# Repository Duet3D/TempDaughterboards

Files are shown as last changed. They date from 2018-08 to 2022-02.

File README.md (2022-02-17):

# TempDaughterboards

The Design files for [PT100](https://www.duet3d.com/PT100_DaughterBoard) and [Thermocouple](https://www.duet3d.com/TC_K_DaughterBoard) daughterboards for Duet boards

Current version 1.1, archive containes older versions

The designs are licensed under the CERN OHL v1.2

Documentation:
https://docs.duet3d.com/Duet3D_hardware/Accessories/Thermocouple_Daughterboard
https://docs.duet3d.com/en/Duet3D_hardware/Accessories/PT100_Temperature_Daughterboard

## Support requests

Please use the [forum](https://forum.duet3d.com) for support requests.

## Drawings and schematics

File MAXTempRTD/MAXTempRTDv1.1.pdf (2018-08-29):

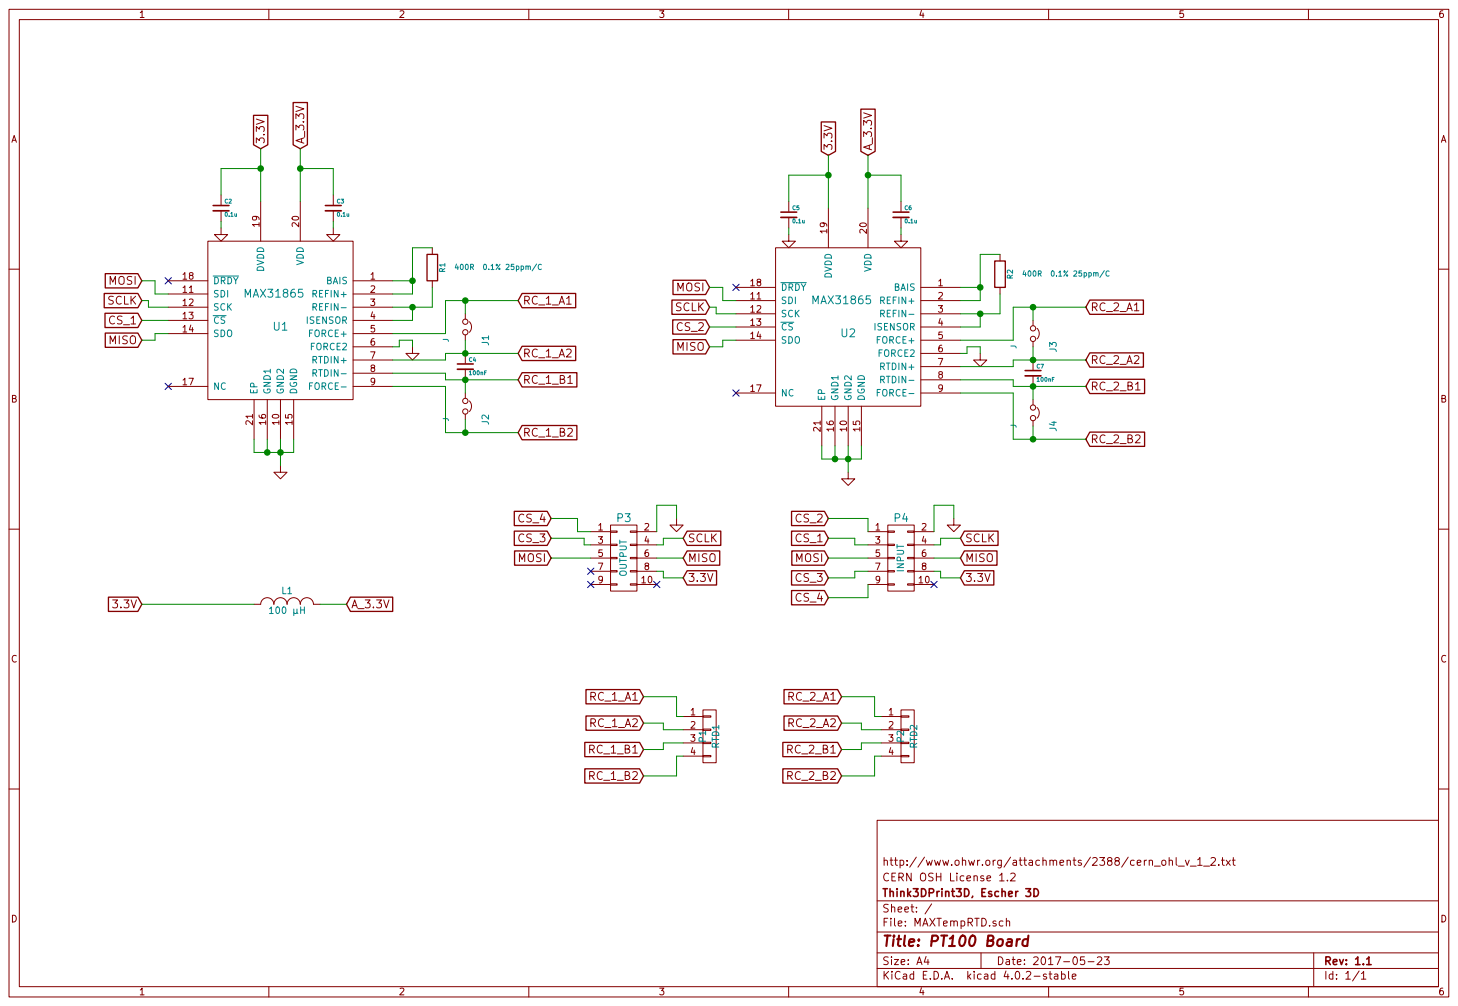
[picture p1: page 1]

http://www.ohwr.org/attachments/2388/cern_ohl_v_1_2.txt
CERN OSH License 1.2
File: MAXTempRTD.sch Sheet: / Think3DPrint3D, Escher 3D

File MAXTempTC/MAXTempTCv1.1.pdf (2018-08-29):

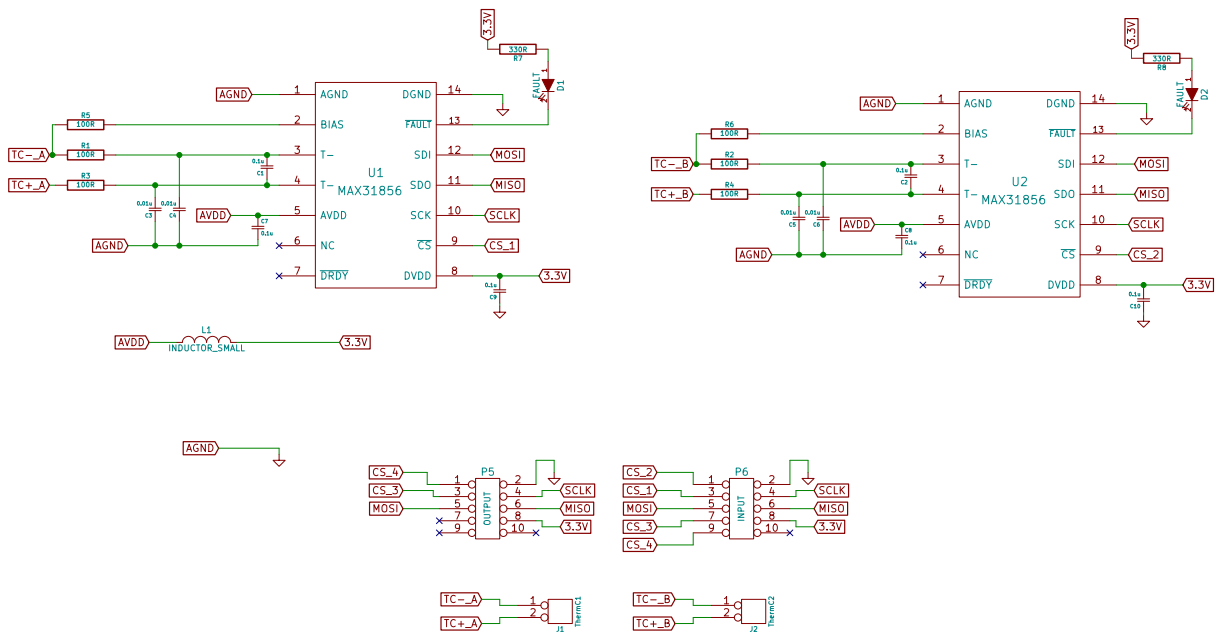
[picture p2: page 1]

http://www.ohwr.org/attachments/2388/cern_ohl_v_1_2.txt
CERN OSH License 1.2
File: MAXTempTC.sch Sheet: / Think3DPrint3D, Escher 3D

Id: 1/1 Title: MAX Temp Thermocouple Board

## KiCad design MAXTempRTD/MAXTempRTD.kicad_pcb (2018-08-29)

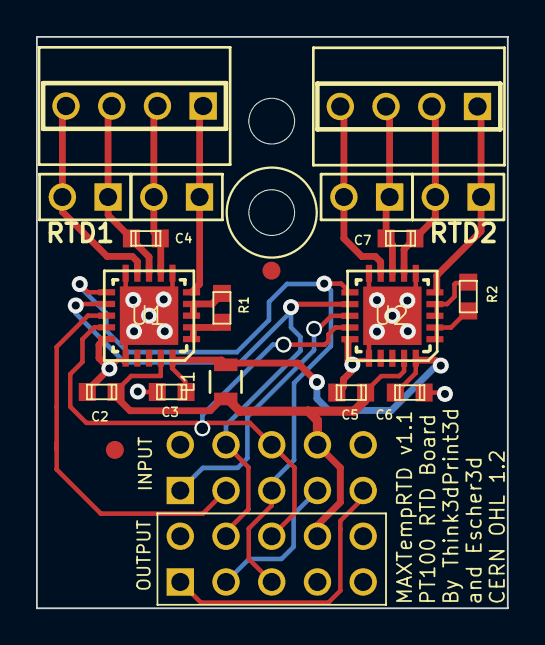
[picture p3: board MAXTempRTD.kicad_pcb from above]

Board: 2 copper layers, 26.2 x 31.7 mm, 19 parts (1 on the bottom side), 22 nets.

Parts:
C2, C3, C5, C6: 0.1u; C_0603
C4, C7: 100nF; C_0603
J1, J2, J3, J4: J; JUMPER
L1: 100 µH; R_0805
P1: RTD1; SCREW_TERMINAL_4x1
P2: RTD2; SCREW_TERMINAL_4x1
P3: OUTPUT; MAX_TEMP_DB
P4: INPUT; MAX_TEMP_DB_inv
R1, R2: 400R 0.1% 25ppm/C; R_0603
U1, U2: MAX31865; QFN20_5x5

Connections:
3.3V: C2.1, C5.1, L1.1, P3.8, P4.8, U1.19, U2.19
A_3.3V: C3.1, C6.1, L1.2, U1.20, U2.20
CS_1: P4.3, U1.13
CS_2: P4.1, U2.13
CS_3: P3.3, P4.7
CS_4: P3.1, P4.9
GND: C2.2, C3.2, C5.2, C6.2, P3.2, P4.2, U1.6, U1.10, U1.15, U1.16, U1.21, U2.6, U2.10, U2.15, U2.16, U2.21
MISO: P3.6, P4.6, U1.14, U2.14
MOSI: P3.5, P4.5, U1.11, U2.11
unnamed: R1.1, U1.1, U1.2
unnamed: R1.2, U1.3, U1.4
unnamed: R2.1, U2.1, U2.2
unnamed: R2.2, U2.3, U2.4
RC_1_A1: J1.1, P1.1, U1.5
RC_1_A2: C4.1, J1.2, P1.2, U1.7
RC_1_B1: C4.2, J2.1, P1.3, U1.8
RC_1_B2: J2.2, P1.4, U1.9
RC_2_A1: J3.1, P2.1, U2.5
RC_2_A2: C7.1, J3.2, P2.2, U2.7
RC_2_B1: C7.2, J4.1, P2.3, U2.8
RC_2_B2: J4.2, P2.4, U2.9
SCLK: P3.4, P4.4, U1.12, U2.12

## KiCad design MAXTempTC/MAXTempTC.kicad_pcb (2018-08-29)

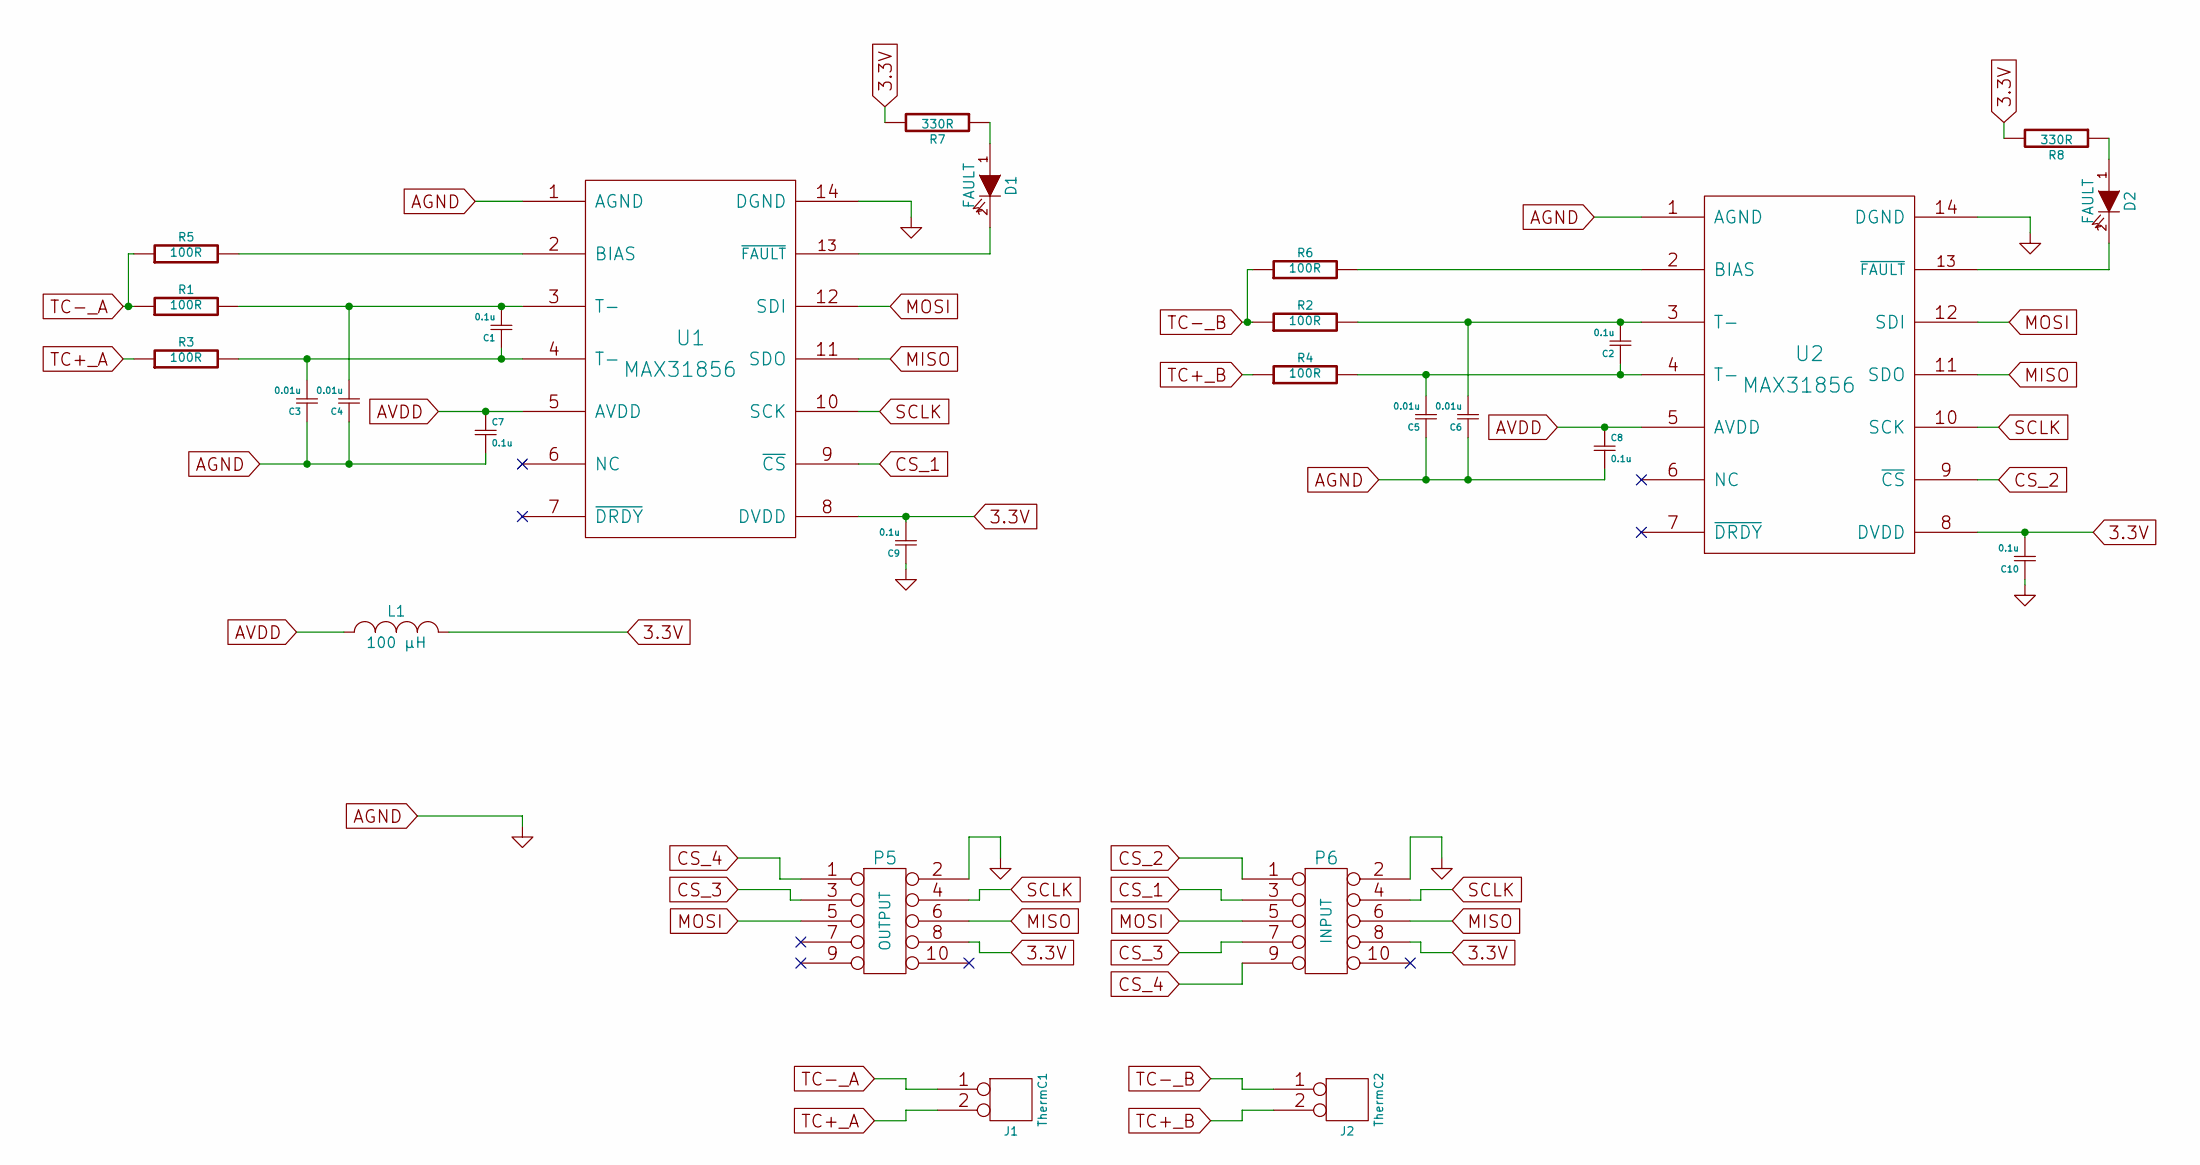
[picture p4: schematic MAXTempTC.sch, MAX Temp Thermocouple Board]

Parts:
C1, C2, C7, C8, C9, C10: 0.1u; C_0603
C3, C4, C5, C6: 0.01u; C_0603
D1, D2: FAULT; D_0603
J1: ThermC1; PIN_ARRAY_2X1
J2: ThermC2; PIN_ARRAY_2X1
L1: 100 µH; R_0805
P5: OUTPUT; MAX_TEMP_DB
P6: INPUT; MAX_TEMP_DB_inv
R1, R2, R3, R4, R5, R6: 100R; R_0603
R7, R8: 330R; R_0603
U1, U2: MAX31856; TSSOP-14

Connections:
3.3V: C9.2, C10.2, L1.2, P5.8, P6.8, R7.2, R8.2, U1.8 (DVDD), U2.8 (DVDD)
AGND: C3.1, C4.1, C5.1, C6.1, C7.2, C8.2, C9.1, C10.1, P5.2, P6.2, U1.1 (AGND), U1.14 (DGND), U2.1 (AGND), U2.14 (DGND)
AVDD: C7.1, C8.1, L1.1, U1.5 (AVDD), U2.5 (AVDD)
CS_1: P6.3, U1.9 (~CS)
CS_2: P6.1, U2.9 (~CS)
CS_3: P5.3, P6.7
CS_4: P5.1, P6.9
MISO: P5.6, P6.6, U1.11 (SDO), U2.11 (SDO)
MOSI: P5.5, P6.5, U1.12 (SDI), U2.12 (SDI)
unnamed: C1.1, C3.2, R3.2, U1.4 (T-)
unnamed: C1.2, C4.2, R1.2, U1.3 (T-)
unnamed: C2.1, C5.2, R4.2, U2.4 (T-)
unnamed: C2.2, C6.2, R2.2, U2.3 (T-)
unnamed: D1.1 (A), R7.1
unnamed: D1.2 (K), U1.13 (~FAULT)
unnamed: D2.1 (A), R8.1
unnamed: D2.2 (K), U2.13 (~FAULT)
unnamed: R5.2, U1.2 (BIAS)
unnamed: R6.2, U2.2 (BIAS)
SCLK: P5.4, P6.4, U1.10 (SCK), U2.10 (SCK)
TC+_A: J1.2 (PM), R3.1
TC+_B: J2.2 (PM), R4.1
TC-_A: J1.1, R1.1, R5.1
TC-_B: J2.1, R2.1, R6.1

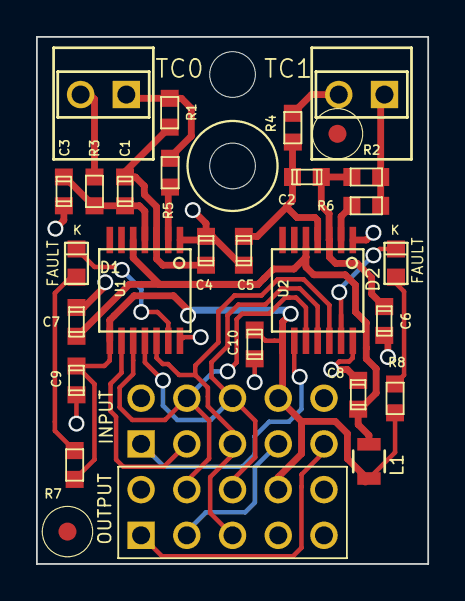
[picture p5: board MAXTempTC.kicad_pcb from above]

Board: 2 copper layers, 21.7 x 29.3 mm, 29 parts (1 on the bottom side), 24 nets.

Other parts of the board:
M3, M3#2: FID; Fiducial_1mm_Dia_2.54mm_Outer_CopperTop

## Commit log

2017-04-01 PT100 and Thermocouple Daughterboards
    Compatible with DuetWifi and DuetEthernet
    [MAXTempRTD.kicad_pcb, MAXTempRTD.sch, MAXTempTC.kicad_pcb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]
2018-08-29 Updated v1.1 source files
    [MAXTempRTD.kicad_pcb, MAXTempRTD.sch, MAXTempTC.kicad_pcb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]

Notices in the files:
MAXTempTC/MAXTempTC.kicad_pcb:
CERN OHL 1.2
